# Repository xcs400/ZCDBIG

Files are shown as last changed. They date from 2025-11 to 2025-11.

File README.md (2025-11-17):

**Detecteur de passage à 0V**<br><br>
Montage avec composants trad. et pcb "simple face" maximalisé pour realisation home-made à la fraiseuse ou par gravure chimique<br>
Le projet Kicad complet est fourni<br>

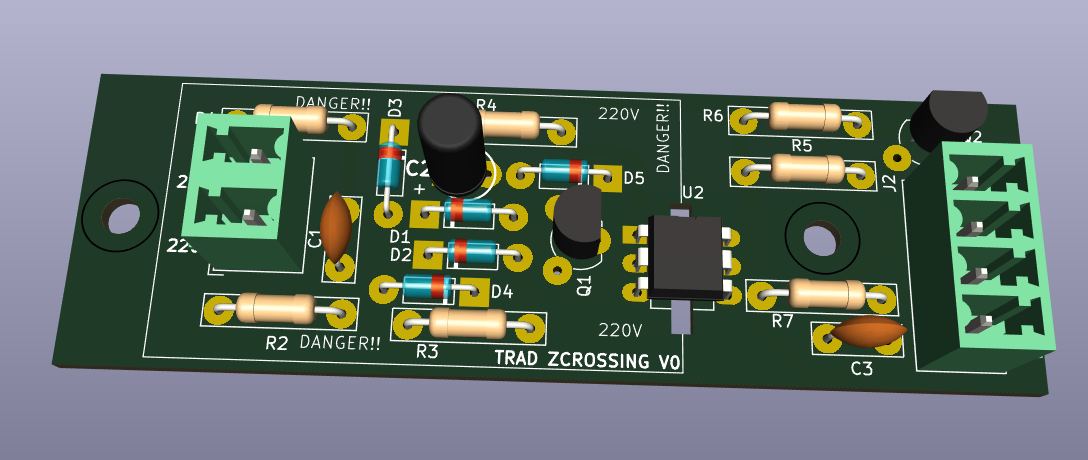
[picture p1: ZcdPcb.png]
PCB

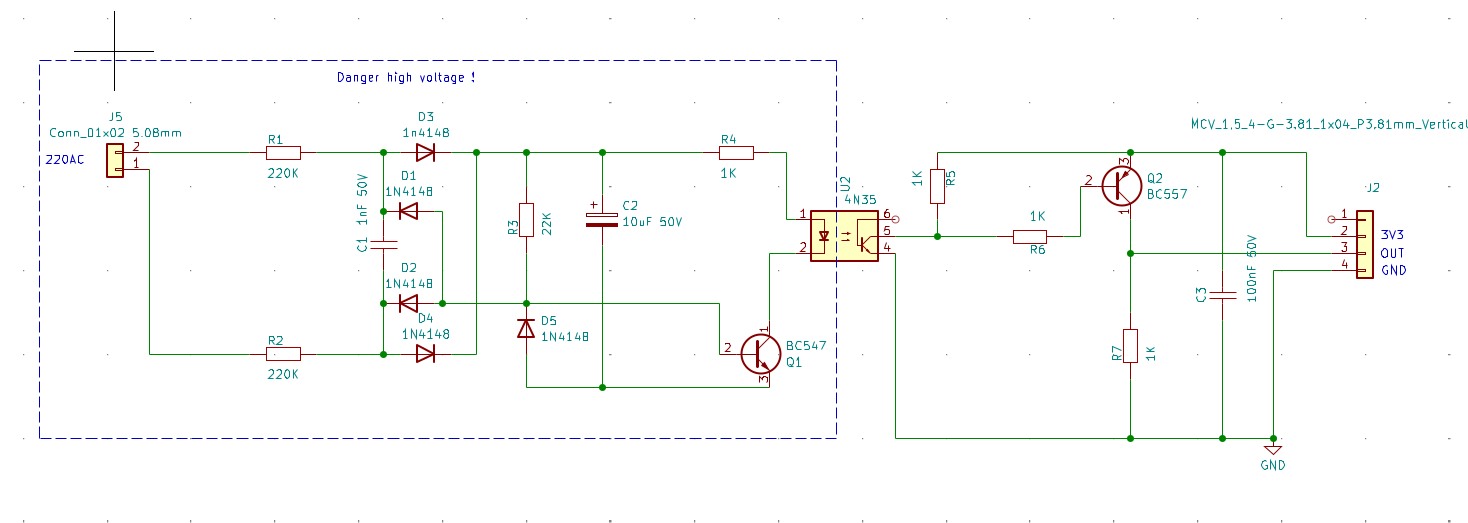
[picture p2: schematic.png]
Schema

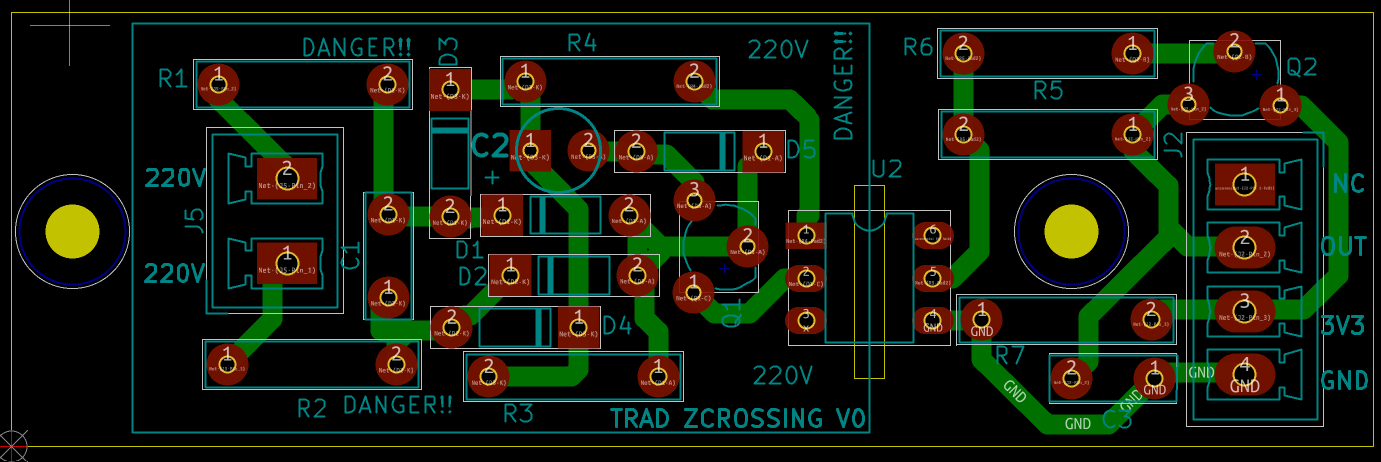
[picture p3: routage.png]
routage

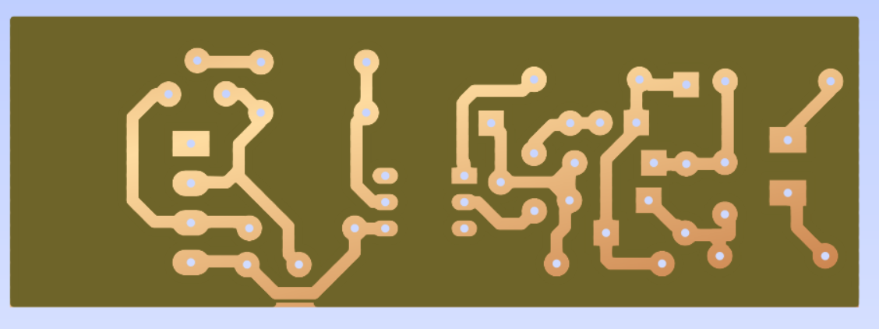
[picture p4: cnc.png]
CNC

relevé:
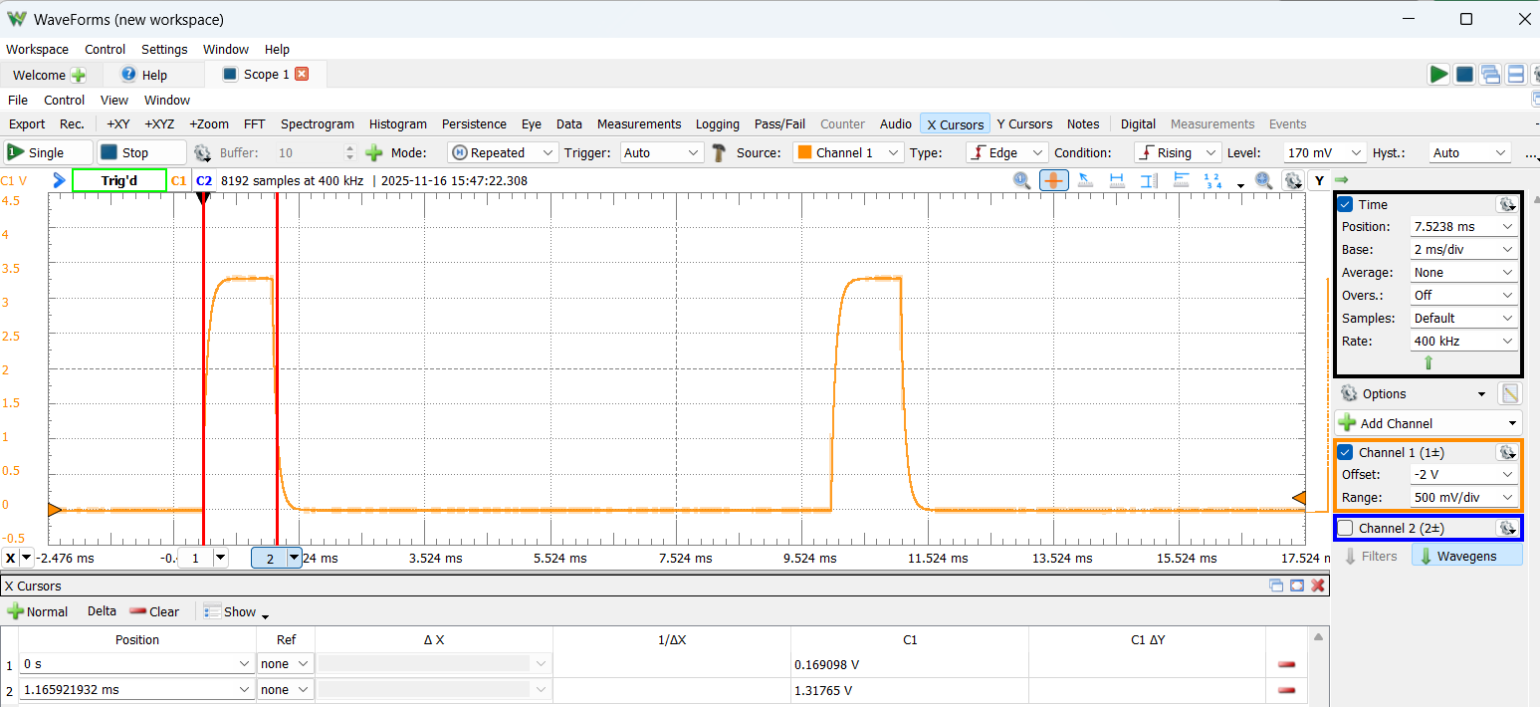
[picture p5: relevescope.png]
scopeCNC


Ce montage a été integré dans mon router solaire pour commander la seconde voie utilisant le SSR.<br>
La premiere voie utilise le SSL commandé en PWM (la detection de passage a 0 est integré dans le SSL).

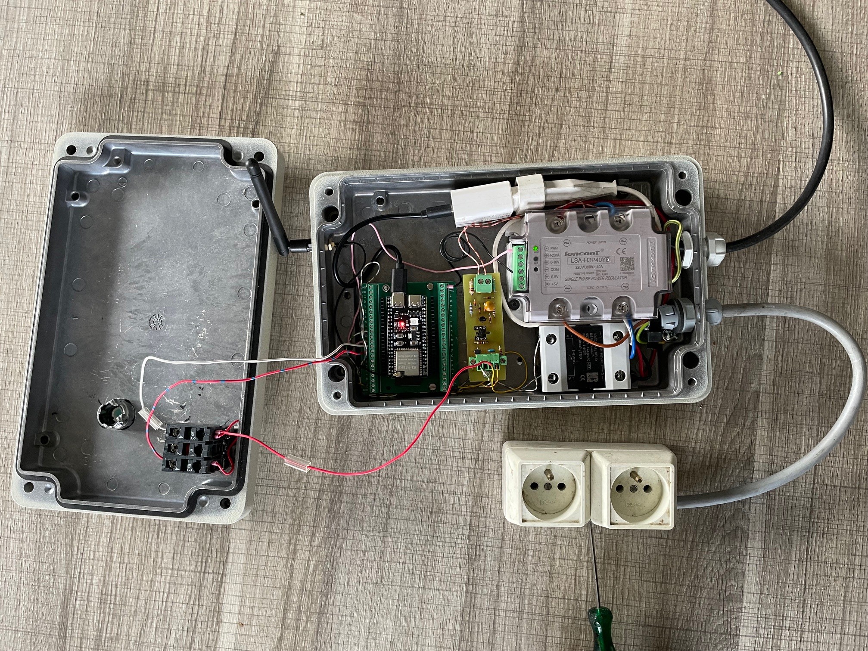
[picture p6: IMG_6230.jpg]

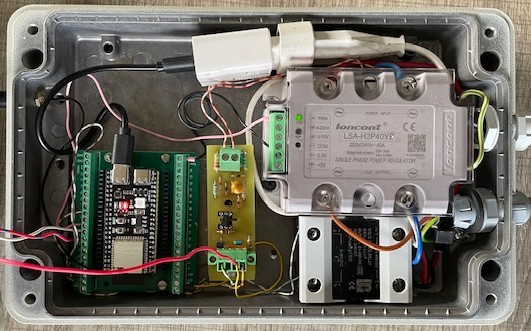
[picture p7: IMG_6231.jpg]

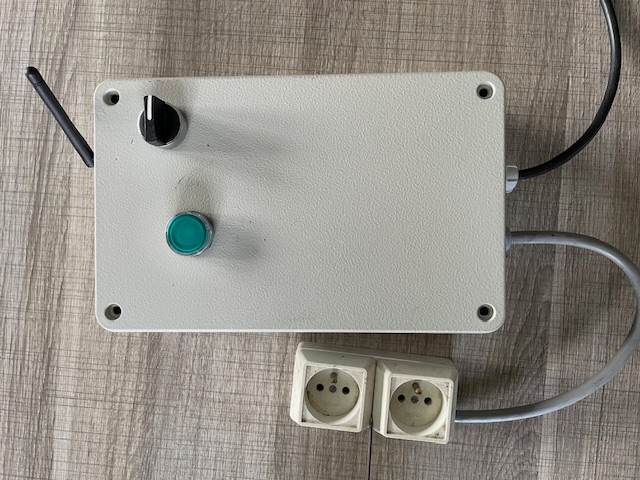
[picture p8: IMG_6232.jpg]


Le logiciel de gestion est une version modifié de YARSOL . <br>
La modification consiste principalement en un module de communication directe vers Tuya ("wifi bidirectional meter") placé dans mon tableau electrique pour acceder à la consomation de la maison.
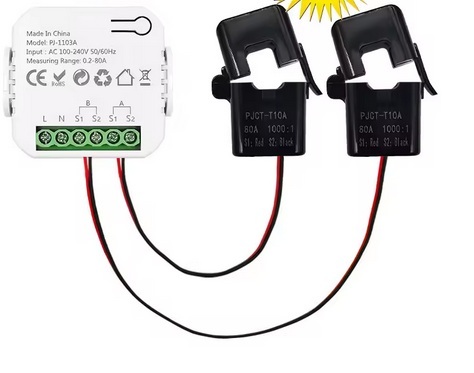
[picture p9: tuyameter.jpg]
tuya meter
  <br>
Le rafraississement des informations de puissance se fait toutes les 3 secondes par wifi  (limite du module tuya), et ne necesssite pas l'utilisation de home assistant ou de serveur MQTT.

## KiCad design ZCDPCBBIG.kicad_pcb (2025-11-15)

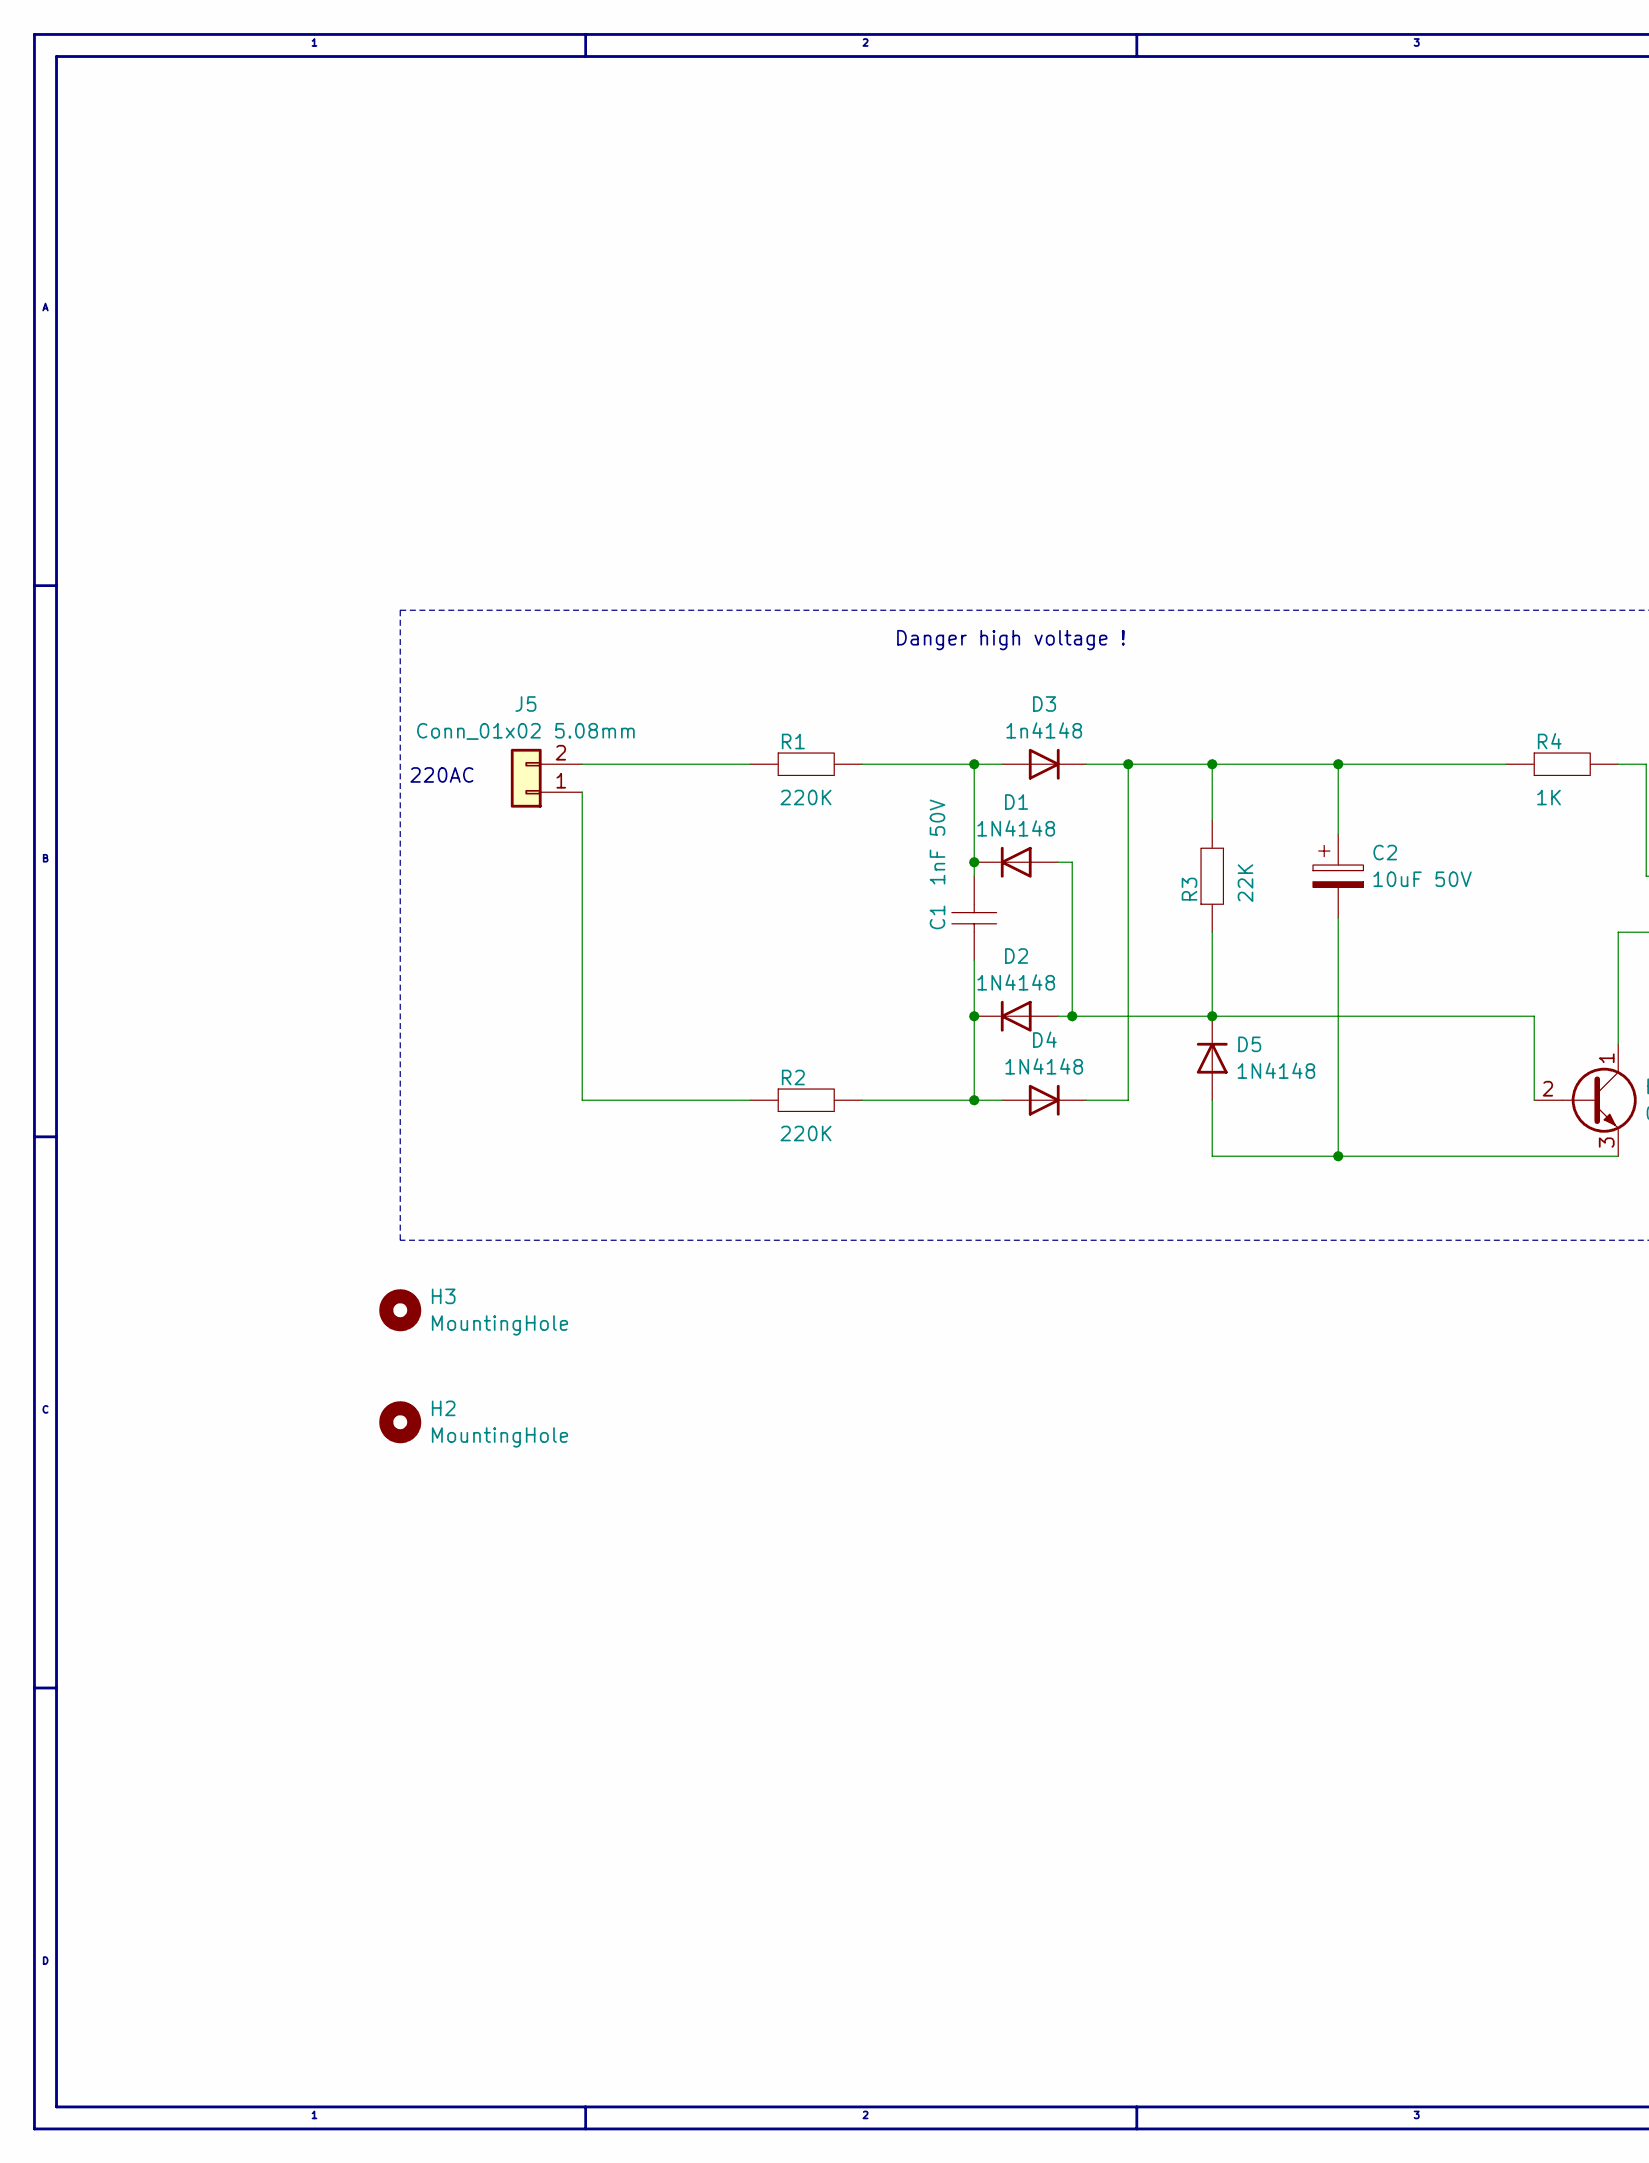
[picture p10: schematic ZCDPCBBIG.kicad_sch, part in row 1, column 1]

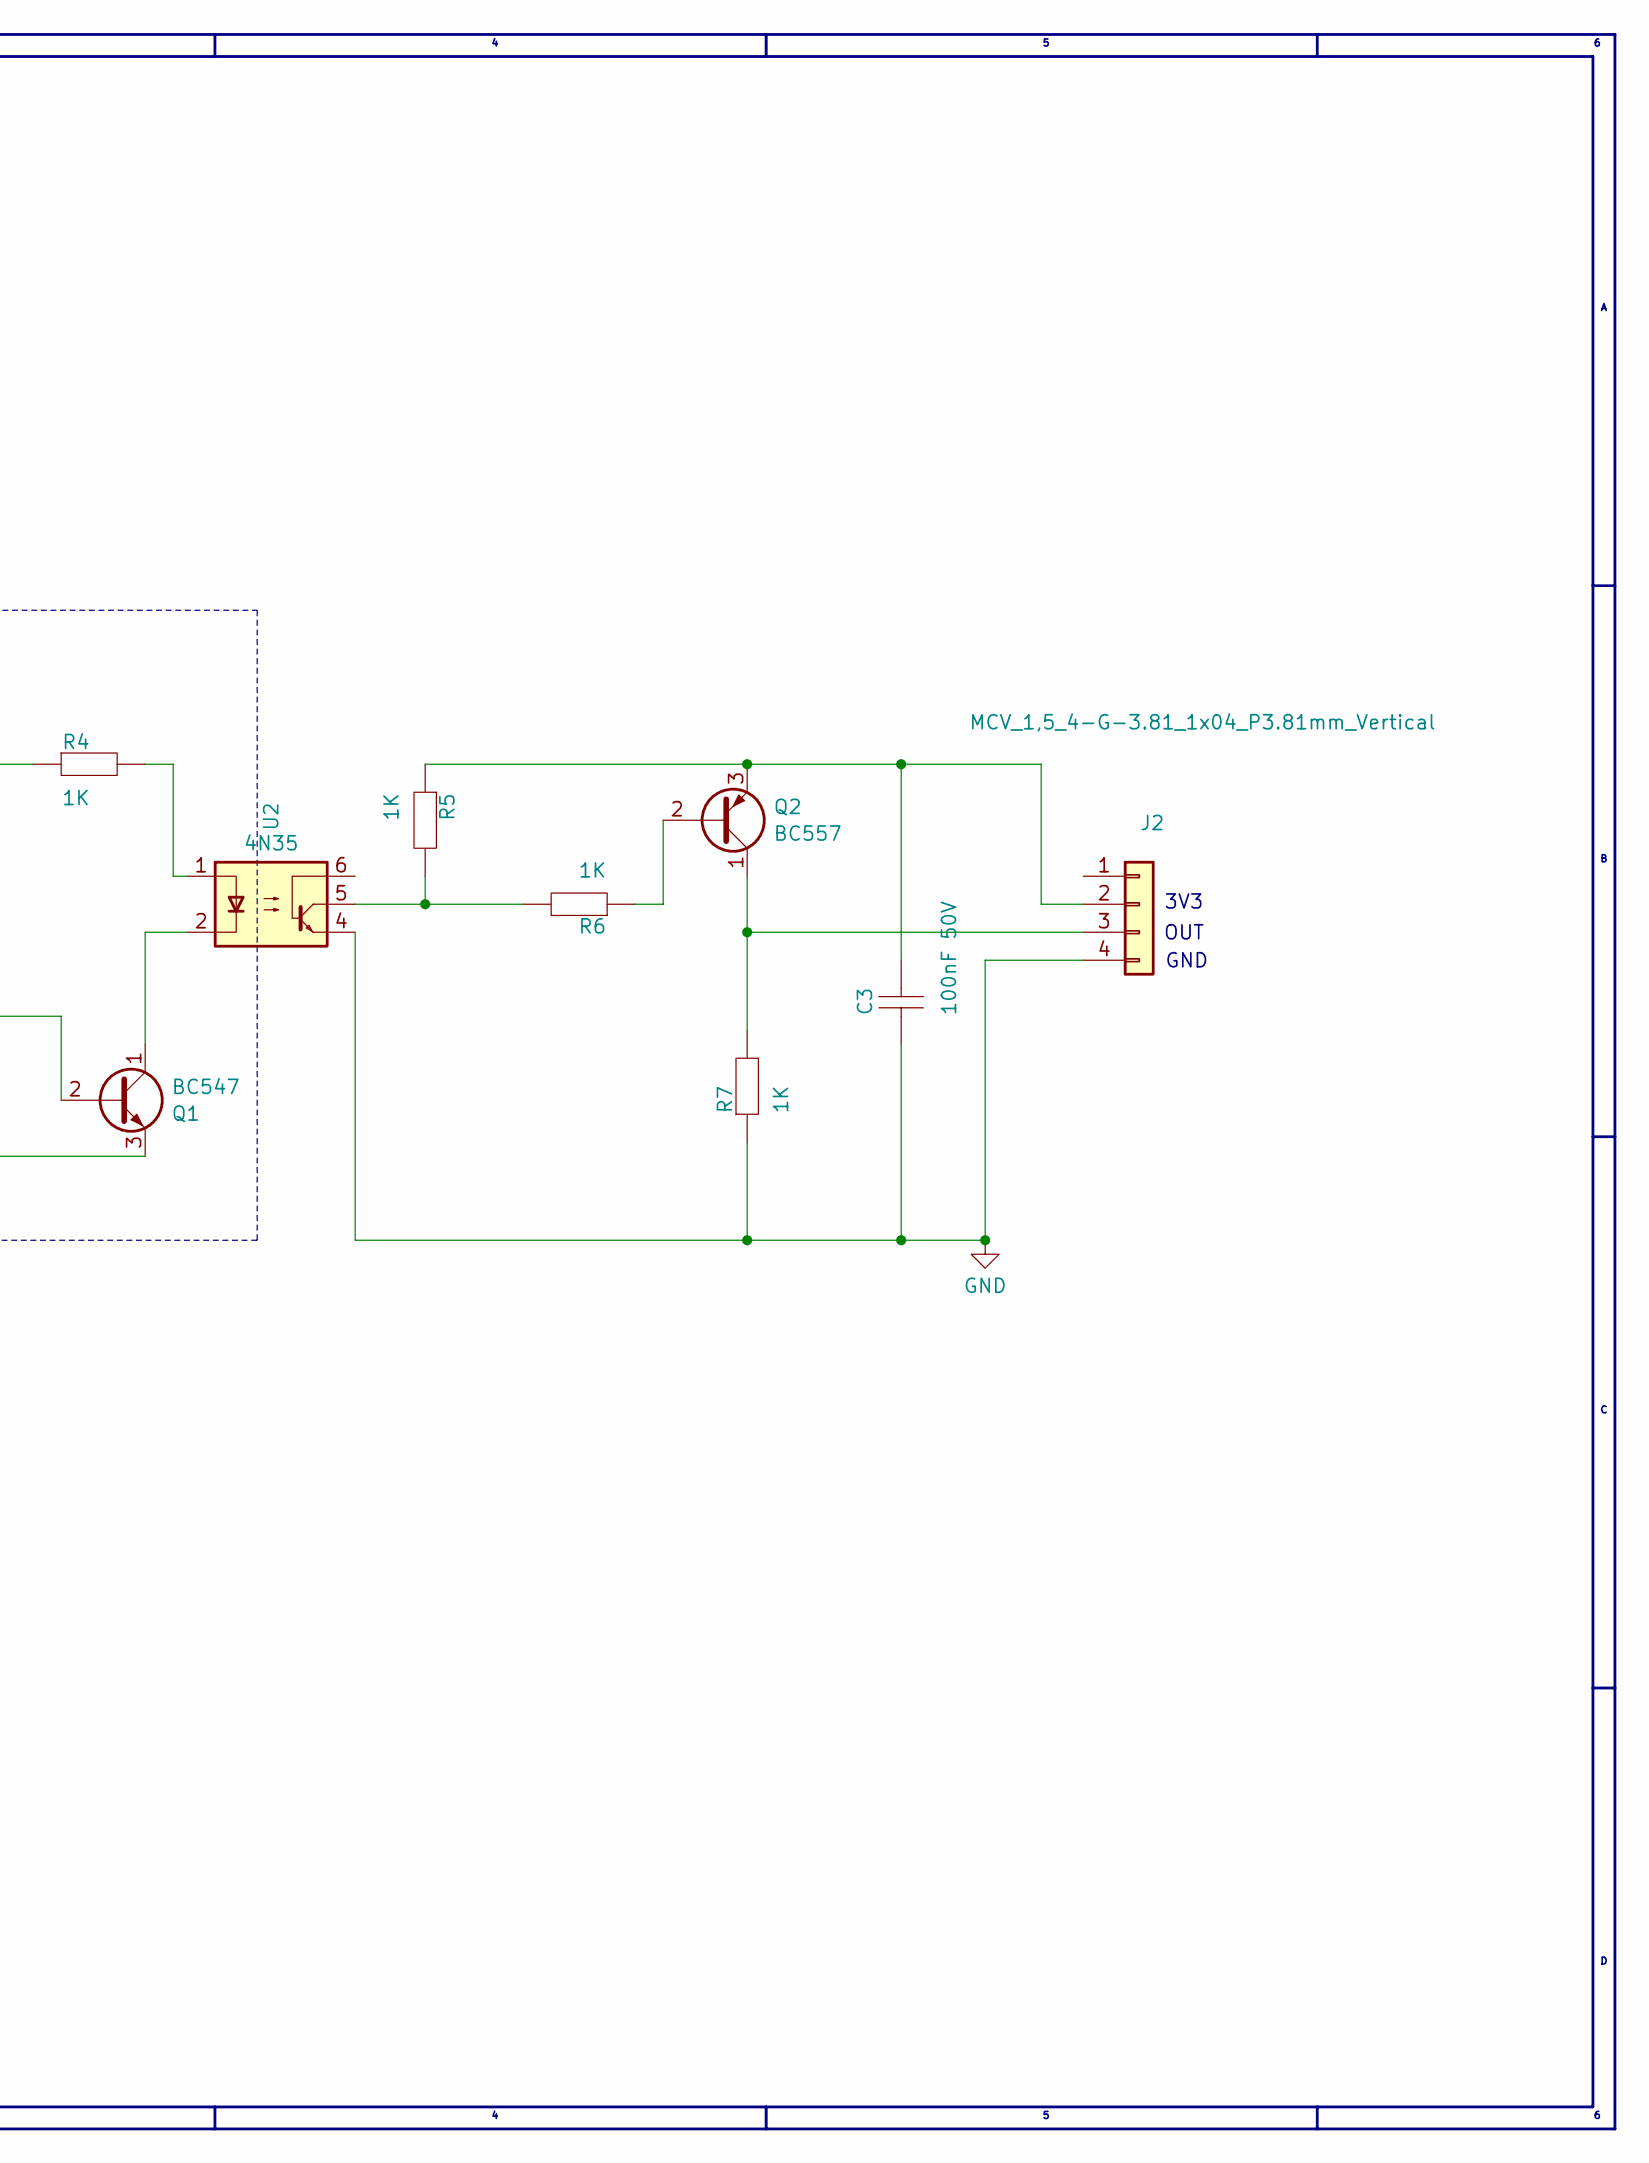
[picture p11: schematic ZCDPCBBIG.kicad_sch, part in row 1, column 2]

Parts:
C1: 1nF 50V; C_Disc_D6.0mm_W2.5mm_P5.00mm_big
C2: 10uF 50V; CAPPRD200W55D500H1350_big
C3: 100nF 50V; C_Disc_D6.0mm_W2.5mm_P5.00mm_big
D1, D2, D4, D5: 1N4148; D_DO-35_SOD27_P7.62mm_Horizontal_big
D3: 1n4148; D_DO-35_SOD27_P7.62mm_Horizontal_big
H2, H3: MountingHole; MountingHole_3.2mm_M3
J2: MCV_1,5_4-G-3.81_1x04_P3.81mm_Vertical; PhoenixContact_MCV_1,5_4-G-3.81_1x04_P3.81mm_Vertical_route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
J5: Conn_01x02 5.08mm; PhoenixContact_MCV_1,5_2-G-5.08_1x02_P5.08mm_Vertical_route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
Q1: BC547; TO-92_Inline_router_big
Q2: BC557; TO-92_Inline_router_big
R1, R2: 220K; R_Axial_DIN0207_L6.3mm_D2.5mm_P10.16mm_Horizontal_big
R3: 22K; R_Axial_DIN0207_L6.3mm_D2.5mm_P10.16mm_Horizontal_big
R4, R5, R6, R7: 1K; R_Axial_DIN0207_L6.3mm_D2.5mm_P10.16mm_Horizontal_big
U2: 4N35; DIP-6_W7.62mm_big

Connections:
GND: C3.1, J2.4, R7.1, U2.4
unnamed: D1.2 (A), D2.2 (A), D5.1 (K), Q1.2 (B), R3.1
unnamed: C1.2, D1.1 (K), D3.2 (A), R1.2
unnamed: C1.1, D2.1 (K), D4.2 (A), R2.2
unnamed: C2.1, D3.1 (K), D4.1 (K), R3.2, R4.1
unnamed: C2.2, D5.2 (A), Q1.3 (E)
unnamed: C3.2, J2.2, Q2.3 (E), R5.1
unnamed: J2.3, Q2.1 (C), R7.2
unnamed: J5.1, R2.1
unnamed: J5.2, R1.1
unnamed: Q1.1 (C), U2.2
unnamed: Q2.2 (B), R6.1
unnamed: R4.2, U2.1
unnamed: R5.2, R6.2, U2.5

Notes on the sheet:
OUT
220AC
Danger high voltage !
3V3
GND

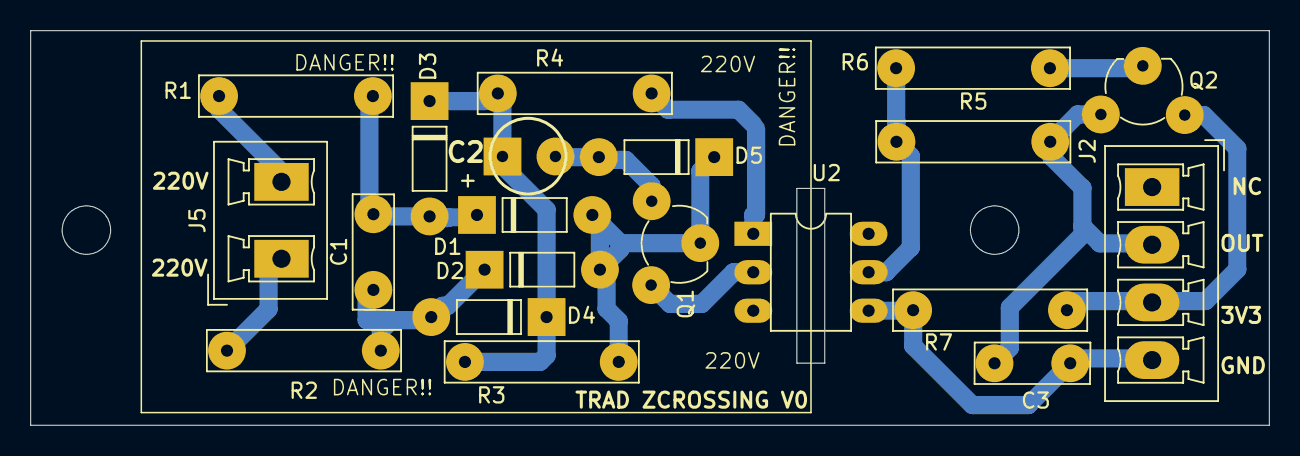
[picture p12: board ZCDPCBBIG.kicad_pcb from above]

Board: 2 copper layers, 81.8 x 26.1 mm, 22 parts (0 on the bottom side), 14 nets.
